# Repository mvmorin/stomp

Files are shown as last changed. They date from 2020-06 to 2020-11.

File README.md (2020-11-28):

# Stomp
Split, staggered column 40% keyboard. Designed in KiCad with symbols and footprints from [keyboard-parts](https://github.com/mvmorin/keyboard-parts) library.

# Features
* Low profile and flat-bottom design to be put on top of laptop keyboards.
* Extra large stagger for pinky columns.
* Based on a standard 40% 4x12 layout but only contains the reachable keys. It should be compatible with most 40% 4x12 layouts.
* Only a single Teensy or Pro-Micro-compatible controller board needed.
* Full FR4 (PCB) design, including backplate, for easy single order manufacturing.
* Both MX and Alps plates.

# PCB and Plate files
The production files for the latest version can be found in the 'gerber' directory. They have been test printed at [JLCPCB](https://jlcpcb.com/). Any notes from the test prints can be found below.

## Test Print Comments
The mounting pin holes for 5-pin MX-switches are bit tighter than I would have preferred. They are perfectly usable with the Ink Blacks I tested them but they will be enlarged in any potential future revisions.

# Licenses


This project is released under the [Creative Commons CC-BY-SA 4.0](https://creativecommons.org/licenses/by-sa/4.0/legalcode) license, Copyright (c) Martin Morin 2020.
Some footprints and symbols are based on parts from the [KiCad libraries](https://kicad-pcb.org/libraries/), released under the same [CC-BY-SA 4.0](https://creativecommons.org/licenses/by-sa/4.0/legalcode) license.

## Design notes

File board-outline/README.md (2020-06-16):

# Board Outline
It based on an export of the switch cutouts and is drawn as a parametric sketch.

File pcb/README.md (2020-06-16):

# Base PCB
The footprints contains all information for the plate. The switch cutouts and the plate silk-screen layer are exported via the *eco1*, *eco2*, and *cmts* layers and are then imported in the backplate PCB drawing. The board-outline/edge-cuts is imported from the *board-outline* directory.

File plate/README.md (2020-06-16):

# Plates
The switch cutouts and the plate silk-screen are imported from the base PCB drawing. The edge-cuts are imported from the *board-outline* directory.

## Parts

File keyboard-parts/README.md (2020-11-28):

# Keyboard Parts
KiCad library of MX and Alps compatible footprints and other miscellaneous footprints and symbols.

# Design
The main focus is the ease of PCB and plate creation. The switch footprints and symbol already have the diodes included. This eliminates almost half of the components and traces. Each switch footprint also comes with the corresponding plate-cutout for both MX and Alps switches as well as a silk-screen layer for the plate. The PCB can then serve as the master for the plate with the corresponding layers being exported for use in the plate design. The cutouts are mainly aimed at PCB/FR4 plates and are/will be dimensioned to accommodate the looser tolerances of PCB-milling.

# Features
* Combined switch-and-diode footprints.
* *eco1*-layer: Outline for MX cutouts.
* *eco2*-layer: Outline for Alps cutouts.
* *cmts*-layer: Silk-screen for plate.

The main benefit of these footprints is the extra information of the keyboard backplate they contain. To easily export these features to the backplate KiCad project, the *eco1*, *eco2*, and *cmts* layers of all other footprints used need to either be empty or contain the corresponding information.

# Known Issues
* ~~MX stabilizer cutout are tight but fully usable.~~
* ~~Mounting pin holes for 5-pin MX switches are tight but fully usable.~~

# Untested Footprints
Footprint features that not have been test printed/manufactured:
* The new 0.1mm larger MX stabilizer cutouts and mounting pin holes for 5-pn MX switches.

# Licenses


The library is released under the [Creative Commons CC-BY-SA 4.0](https://creativecommons.org/licenses/by-sa/4.0/legalcode) license, Copyright (c) Martin Morin 2020.
Some footprints and symbols are based on parts from the [KiCad libraries](https://kicad-pcb.org/libraries/), released under the same [CC-BY-SA 4.0](https://creativecommons.org/licenses/by-sa/4.0/legalcode) license.

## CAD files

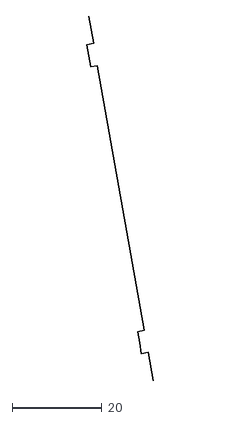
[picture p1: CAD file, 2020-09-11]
board-outline/magnet-sidecuts.dxf
14.7 x 81.2

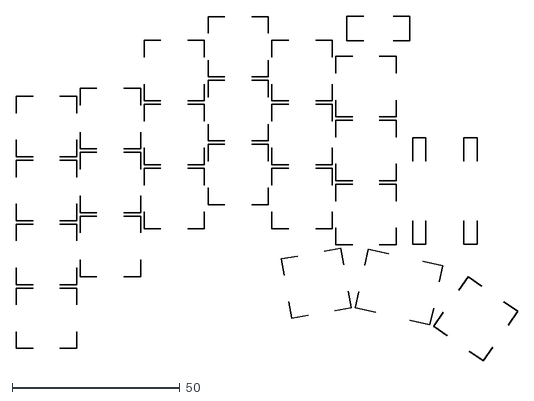
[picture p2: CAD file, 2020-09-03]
plate/outlines/pcb-Cmts_User.dxf
149.5 x 102.7

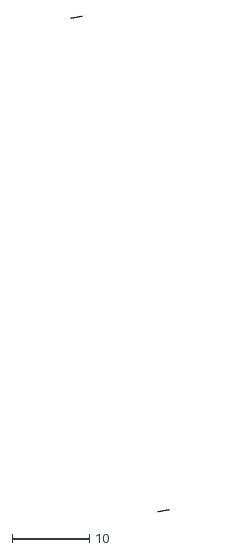
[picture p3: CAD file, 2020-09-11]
board-outline/magnet-pos.dxf
12.8 x 64.3

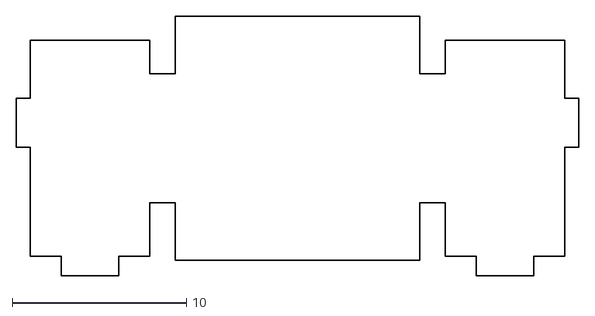
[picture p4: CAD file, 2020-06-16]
keyboard-parts/plate-cutouts/mx_stab_2u.dxf
32.3 x 14.9

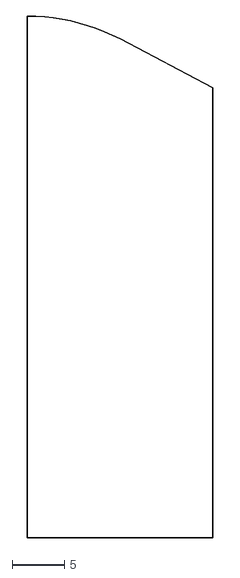
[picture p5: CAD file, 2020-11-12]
mcu-dummy/outline.dxf
17.8 x 49.9

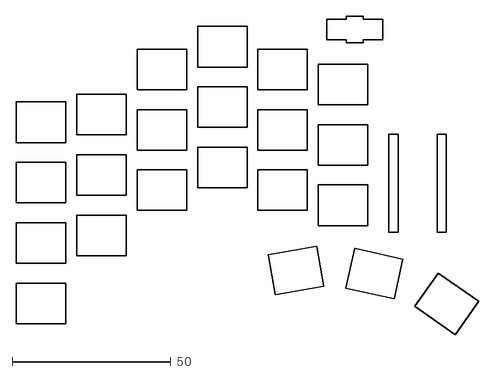
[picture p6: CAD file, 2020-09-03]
plate/outlines/pcb-Eco2_User.dxf
145.8 x 100.4

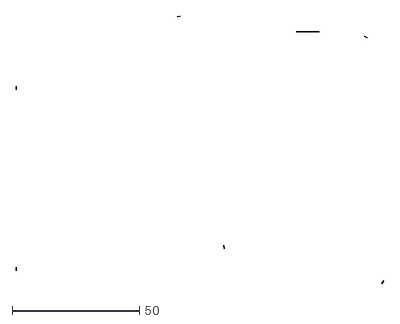
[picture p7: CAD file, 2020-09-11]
board-outline/header-pos.dxf
144.8 x 105.3

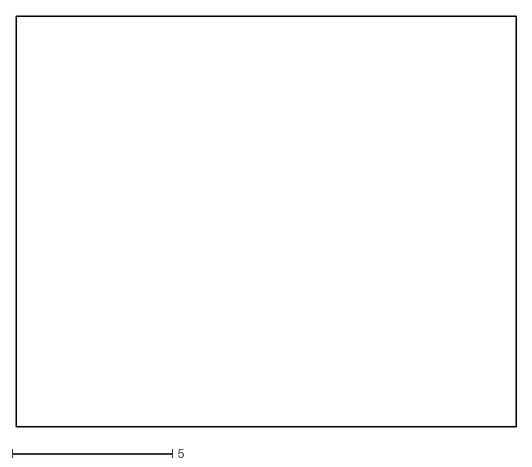
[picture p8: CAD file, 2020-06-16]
keyboard-parts/plate-cutouts/alps.dxf
15.6 x 12.8

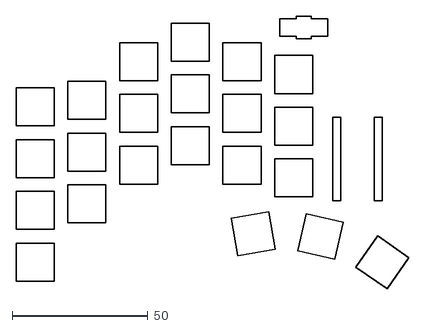
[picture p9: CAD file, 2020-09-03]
plate/outlines/pcb-Eco1_User.dxf
144.7 x 100.5

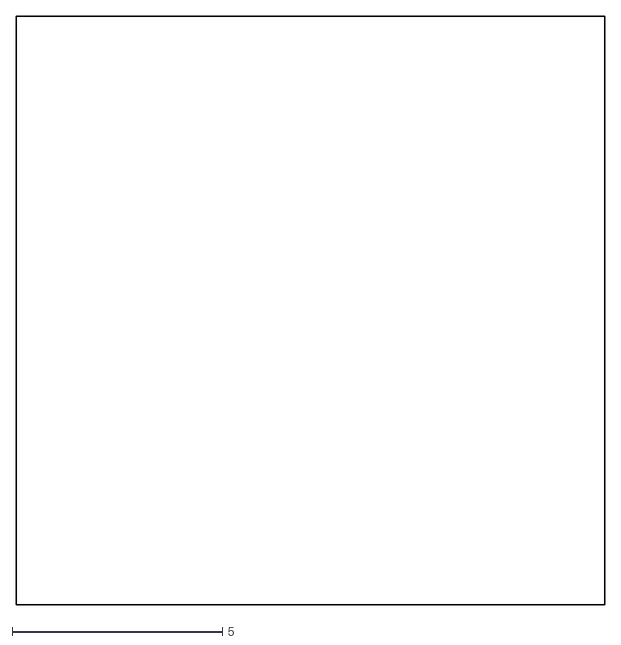
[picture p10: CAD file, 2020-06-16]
keyboard-parts/plate-cutouts/mx.dxf
14.0 x 14.0

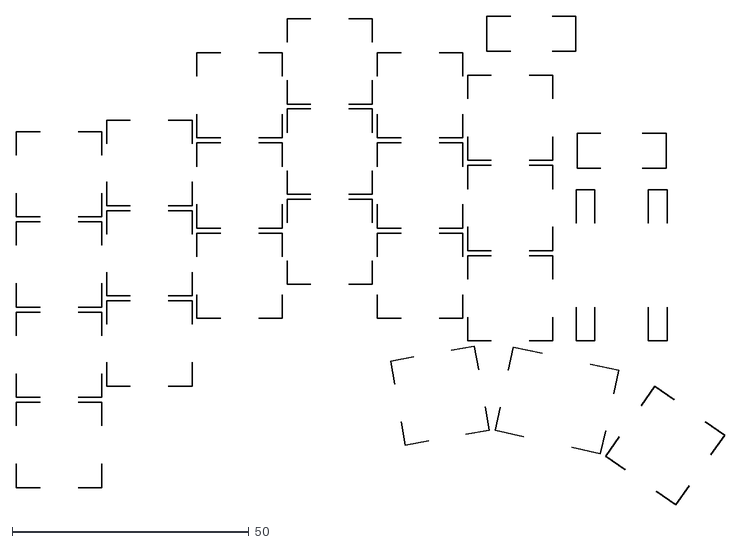
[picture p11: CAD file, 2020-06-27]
plate/outlines/plate-silk.dxf
149.5 x 103.2

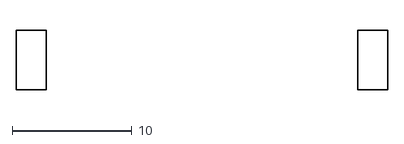
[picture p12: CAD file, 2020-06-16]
keyboard-parts/plate-cutouts/alps_stab_2u.dxf
31.0 x 5.00

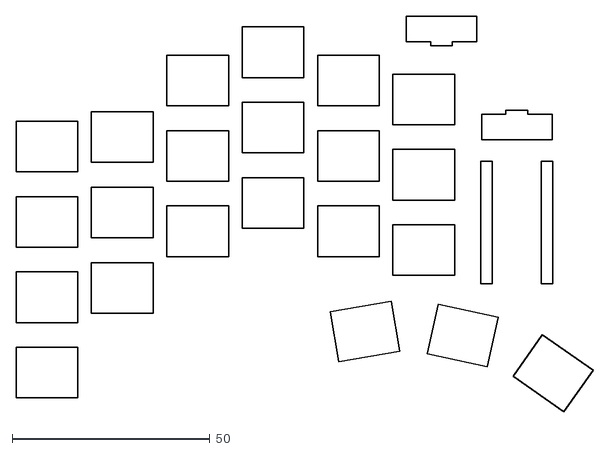
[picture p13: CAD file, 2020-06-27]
plate/outlines/alps-cutouts.dxf
145.8 x 99.9

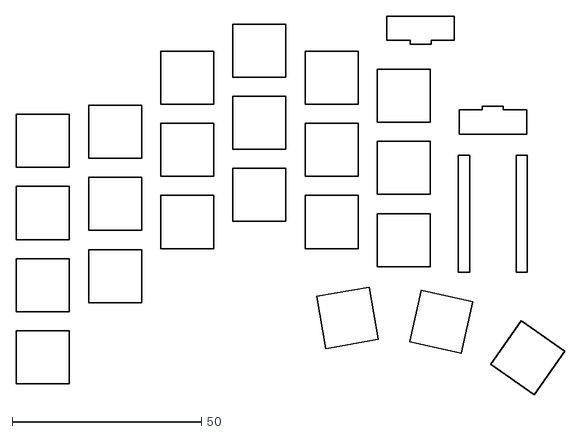
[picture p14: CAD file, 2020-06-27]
plate/outlines/mx-cutouts.dxf
144.7 x 99.9

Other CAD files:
keyboard-parts/plate-cutouts/plate_cutouts.FCStd
mcu-dummy/mcu-dummy-outline.fcstd
board-outline/board-outline.FCStd
board-outline/board-outline.dxf
board-outline/header_pos.dxf

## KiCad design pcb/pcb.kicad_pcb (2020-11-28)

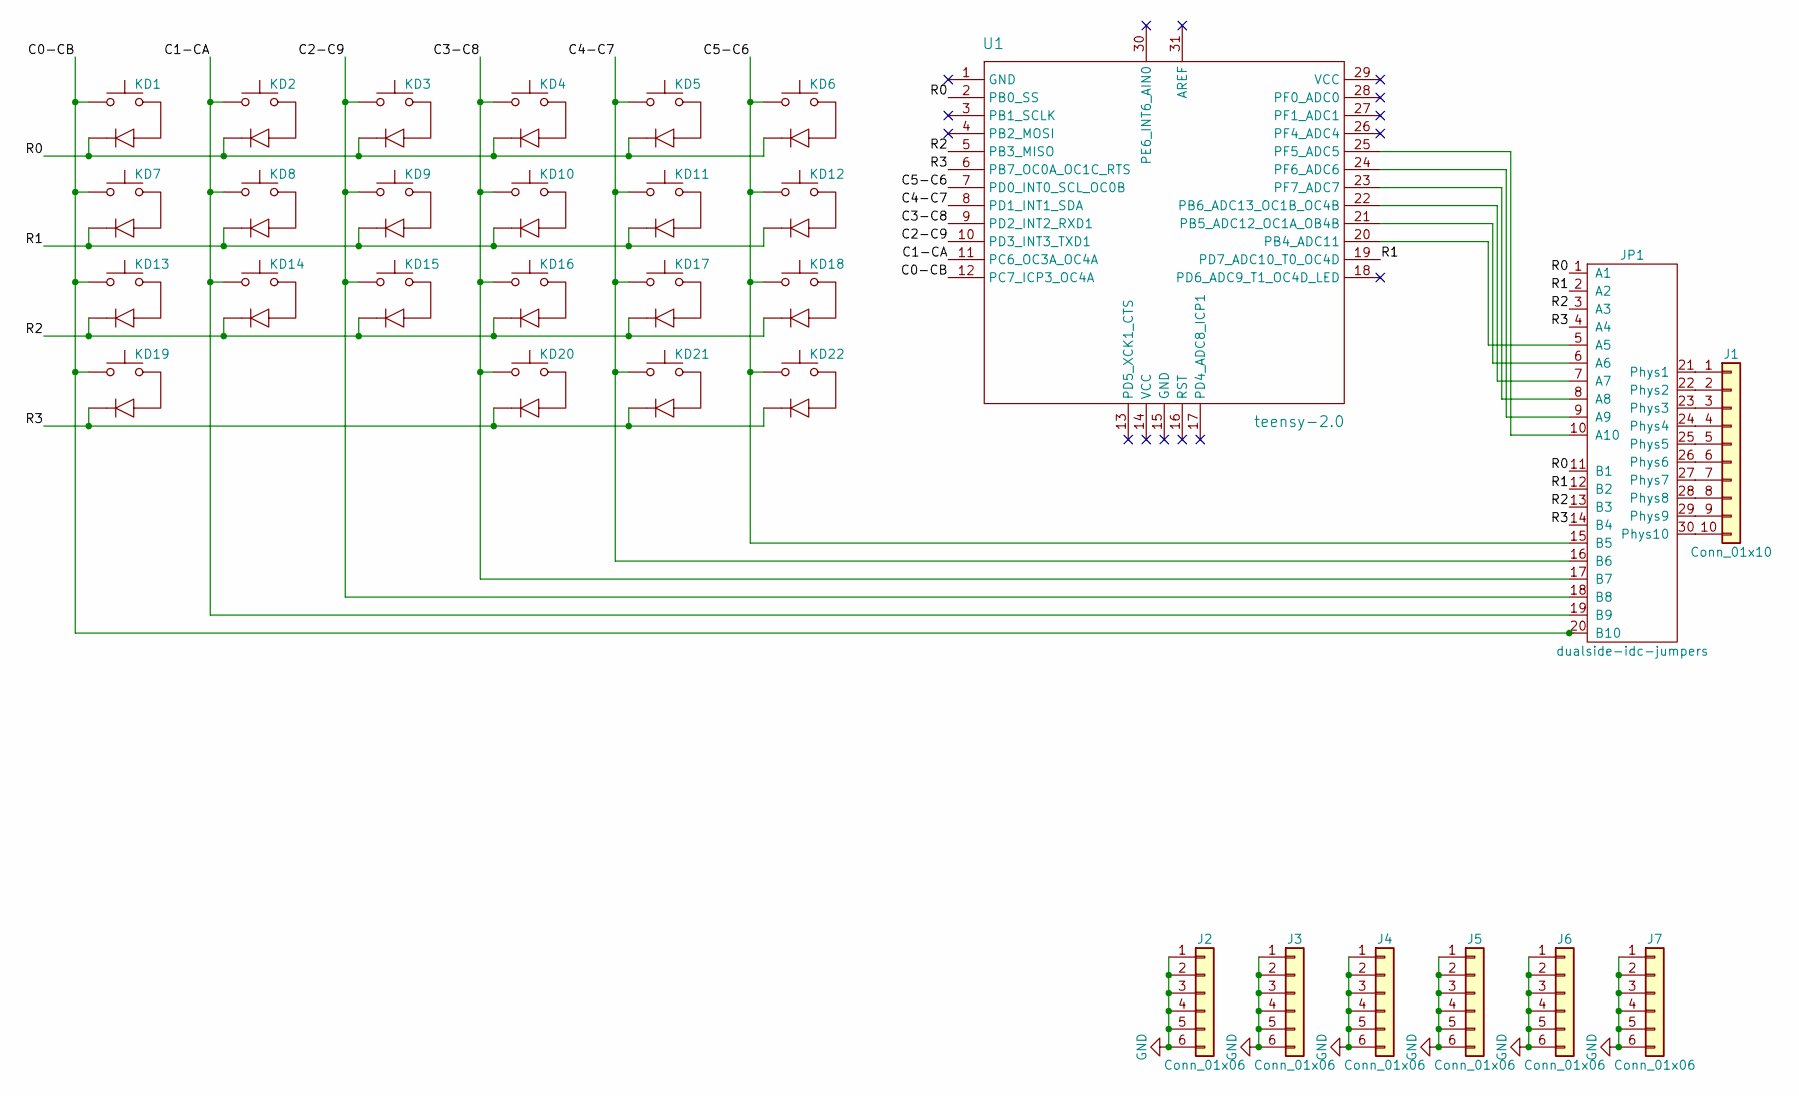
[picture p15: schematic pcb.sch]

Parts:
J1: Conn_01x10; idc-header-dualside_2x05_2.54mm
J2, J3, J4, J5, J6, J7: Conn_01x06; header_sym_1x06_2.54mm
JP1: dualside-idc-jumpers
KD1, KD2, KD3, KD4, KD5, KD6, KD7, KD8, KD9, KD10, KD11, KD12, KD13, KD14, KD15, KD16, KD17, KD18, KD19, KD20, KD22: switch-w-diode; mxalps_w_diode_R_100U_dualside
KD21: switch-w-diode; mxalps_w_diode_R_125U_dualside
U1: teensy-2.0; teensy2.0_dualside

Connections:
/C0-CB: JP1.20 (B10), KD1.1 (A), KD7.1 (A), KD13.1 (A), KD19.1 (A), U1.12 (PC7_ICP3_OC4A)
/C1-CA: JP1.19 (B9), KD2.1 (A), KD8.1 (A), KD14.1 (A), U1.11 (PC6_OC3A_OC4A)
/C2-C9: JP1.18 (B8), KD3.1 (A), KD9.1 (A), KD15.1 (A), U1.10 (PD3_INT3_TXD1)
/C3-C8: JP1.17 (B7), KD4.1 (A), KD10.1 (A), KD16.1 (A), KD20.1 (A), U1.9 (PD2_INT2_RXD1)
/C4-C7: JP1.16 (B6), KD5.1 (A), KD11.1 (A), KD17.1 (A), KD21.1 (A), U1.8 (PD1_INT1_SDA)
/C5-C6: JP1.15 (B5), KD6.1 (A), KD12.1 (A), KD18.1 (A), KD22.1 (A), U1.7 (PD0_INT0_SCL_OC0B)
/R0: JP1.1 (A1), JP1.11 (B1), KD1.2 (K), KD2.2 (K), KD3.2 (K), KD4.2 (K), KD5.2 (K), KD6.2 (K), U1.2 (PB0_SS)
/R1: JP1.2 (A2), JP1.12 (B2), KD7.2 (K), KD8.2 (K), KD9.2 (K), KD10.2 (K), KD11.2 (K), KD12.2 (K), U1.19 (PD7_ADC10_T0_OC4D)
/R2: JP1.3 (A3), JP1.13 (B3), KD13.2 (K), KD14.2 (K), KD15.2 (K), KD16.2 (K), KD17.2 (K), KD18.2 (K), U1.5 (PB3_MISO)
/R3: JP1.4 (A4), JP1.14 (B4), KD19.2 (K), KD20.2 (K), KD21.2 (K), KD22.2 (K), U1.6 (PB7_OC0A_OC1C_RTS)
GND: J2.1, J2.2, J2.3, J2.4, J2.5, J2.6, J3.1, J3.2, J3.3, J3.4, J3.5, J3.6, J4.1, J4.2, J4.3, J4.4, J4.5, J4.6, J5.1, J5.2, J5.3, J5.4, J5.5, J5.6, J6.1, J6.2, J6.3, J6.4, J6.5, J6.6, J7.1, J7.2, J7.3, J7.4, J7.5, J7.6
unnamed: J1.1, JP1.21 (Phys1)
unnamed: J1.2, JP1.22 (Phys2)
unnamed: J1.3, JP1.23 (Phys3)
unnamed: J1.4, JP1.24 (Phys4)
unnamed: J1.5, JP1.25 (Phys5)
unnamed: J1.6, JP1.26 (Phys6)
unnamed: J1.7, JP1.27 (Phys7)
unnamed: J1.8, JP1.28 (Phys8)
unnamed: J1.9, JP1.29 (Phys9)
unnamed: J1.10, JP1.30 (Phys10)
unnamed: JP1.5 (A5), U1.20 (PB4_ADC11)
unnamed: JP1.6 (A6), U1.21 (PB5_ADC12_OC1A_OB4B)
unnamed: JP1.7 (A7), U1.22 (PB6_ADC13_OC1B_OC4B)
unnamed: JP1.8 (A8), U1.23 (PF7_ADC7)
unnamed: JP1.9 (A9), U1.24 (PF6_ADC6)
unnamed: JP1.10 (A10), U1.25 (PF5_ADC5)

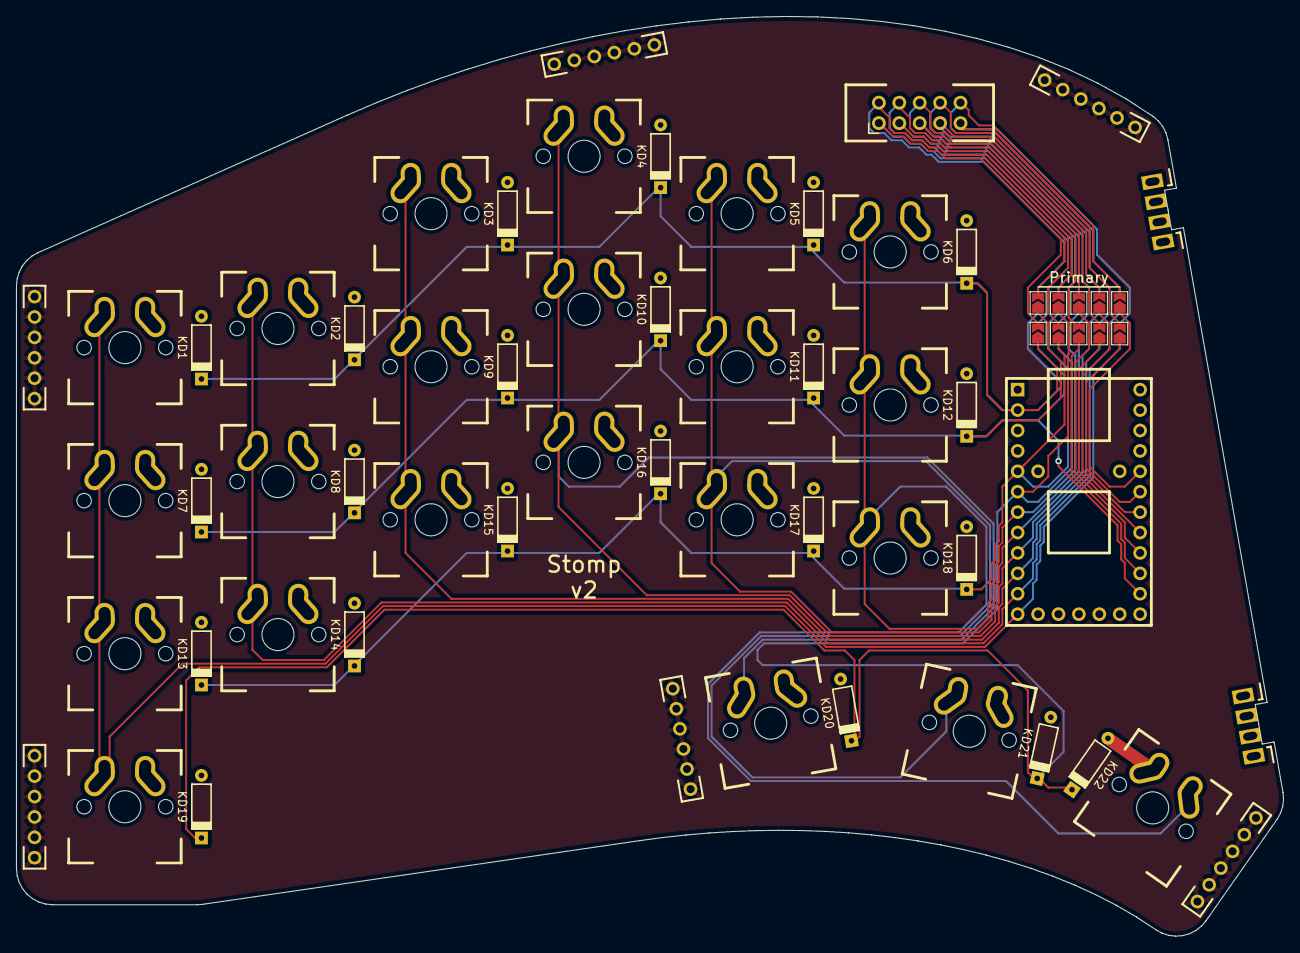
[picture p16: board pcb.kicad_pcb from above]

Board: 2 copper layers, 157.7 x 114.5 mm, 31 parts (1 on the bottom side), 27 nets.

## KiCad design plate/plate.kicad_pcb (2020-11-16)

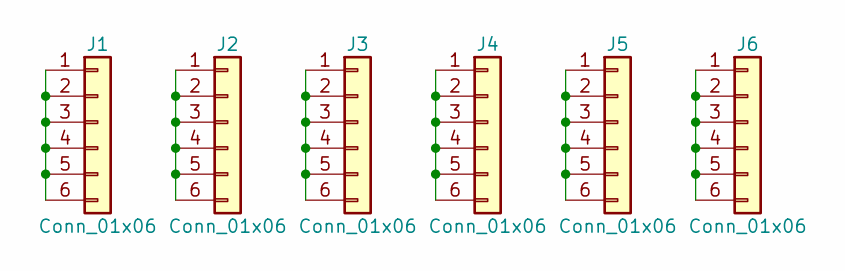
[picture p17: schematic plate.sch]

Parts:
J1, J2, J3, J4, J5, J6: Conn_01x06; header_sym_1x06_2.54mm

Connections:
unnamed: J1.1, J1.2, J1.3, J1.4, J1.5, J1.6
unnamed: J2.1, J2.2, J2.3, J2.4, J2.5, J2.6
unnamed: J3.1, J3.2, J3.3, J3.4, J3.5, J3.6
unnamed: J4.1, J4.2, J4.3, J4.4, J4.5, J4.6
unnamed: J5.1, J5.2, J5.3, J5.4, J5.5, J5.6
unnamed: J6.1, J6.2, J6.3, J6.4, J6.5, J6.6

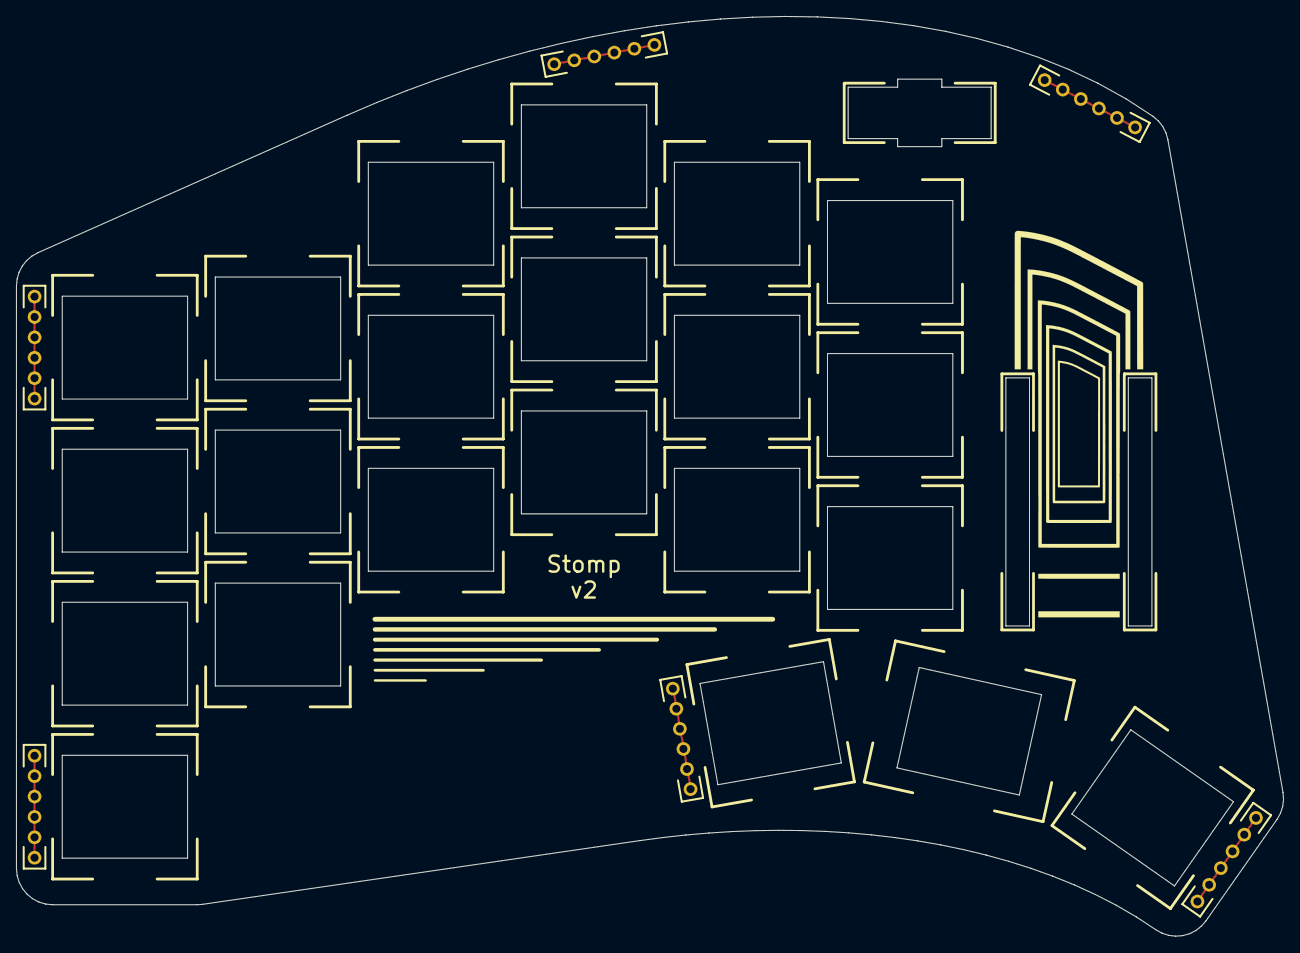
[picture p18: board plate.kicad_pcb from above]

Board: 2 copper layers, 157.7 x 114.5 mm, 6 parts (0 on the bottom side), 6 nets.

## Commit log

2020-06-16 Squashed 'keyboard-parts/' content from commit 7592995
    git-subtree-dir: keyboard-parts
    git-subtree-split: 75929951316423486571924b044501165a41824c
    [alps.dxf, alps_stab_2u.dxf, mx.dxf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]
2020-06-16 Create schematic and start on board
    [pcb.kicad_pcb, pcb.sch]
2020-06-21 Add/remove teensy and header footprints for dualsided keyboards
2020-06-21 Final routing of base pcb. Outline left.
    [pcb.kicad_pcb, pcb.sch]
2020-06-21 Finish base pcb, decorations left
    [board-outline.FCStd, board-outline.dxf, pcb.kicad_pcb]
2020-06-25 Add/update double sided footprints
2020-06-25 Add headers for board interconnect
    [pcb.kicad_pcb, pcb.sch]
2020-06-25 Rotate header to avoid twisting ribbon cable
    [pcb.kicad_pcb]
2020-06-26 Fatter silk and tighter headers cutouts in teensy and IDC
2020-06-26 Add 1x6 header and fix reference in teensy
2020-06-26 Update board outline
    [board-outline.FCStd, board-outline.dxf, pcb.kicad_pcb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]
2020-06-26 Add logos to main pcb
    [pcb.kicad_pcb]
2020-06-27 Add plate
    [alps-cutouts.dxf, mx-cutouts.dxf, pcb.kicad_pcb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]
2020-06-27 Update component 3d models
    [pcb.kicad_pcb, pcb.sch, plate.kicad_pcb]
2020-06-27 Remove arcs on silk
    JLCPCB's gerber viewer draws arcs reversed, might not be a real problem
    but why bother
    [pcb.kicad_pcb, plate.kicad_pcb]
2020-06-27 Add gerbers
2020-07-13 Fix minor silk-screen misses and alignment
    [pcb.kicad_pcb, plate.kicad_pcb]
2020-07-14 Change board outline
    [board-outline.FCStd, board-outline.dxf, pcb-Cmts_User.dxf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]
2020-07-14 Fix one header
    [pcb.kicad_pcb, plate.kicad_pcb]
2020-07-16 Finish refinement of board outline
    [board-outline.FCStd, board-outline.dxf, pcb-Cmts_User.dxf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]
2020-07-16 Change pin for column B to avoid teensy LED
    [pcb.kicad_pcb, pcb.sch]
2020-07-16 Slight reposition and reroute of inter-pcb-header
    [pcb-Cmts_User.dxf, pcb-Eco1_User.dxf, pcb-Eco2_User.dxf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]
2020-09-03 Use single IDC header and prep outline for magnets
    [board-outline.FCStd, board-outline.dxf, pcb-Cmts_User.dxf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]
2020-09-11 Add higher resolution outline curves and magnet supports
    [board-outline.FCStd, board-outline.dxf, magnet-sidecuts.dxf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]
2020-11-12 Add two row teensy footprint for mcu-dummy
2020-11-12 Add mcu-dummy for secondary side and new logos on plate
    [mcu-dummy-outline.fcstd, mcu-dummy.kicad_pcb, outline.dxf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]
2020-11-13 Change line widths of graphics to balance the look better
    [mcu-dummy.kicad_pcb, plate.kicad_pcb]
2020-11-16 Update version number to v2 and add new gerbers
    [mcu-dummy.kicad_pcb, pcb.kicad_pcb, plate.kicad_pcb]
2020-11-28 Squashed 'keyboard-parts/' changes from 7592995..d7591ea
    d7591ea Update README.md
    9f18485 Add two row teensy footprint for mcu-dummy
    8ce1f52 Add higher resolution outline curves and magnet supports
    7473e23 Use single IDC header and prep outline for magnets
    80d8032 Update component 3d models
    6c1f2c6 Add 1x6 header and fix reference in teensy
    bab489d Fatter silk and tighter headers cutouts in teensy and IDC
    47fce25 Add/update double sided footprints
    03ca6c9 Add/remove teensy and header footprints for dualsided keyboards
    792f574 Add new double sided parts
    git-subtree-split: d7591ea33b660919236fcc919a326ff28b49c6a0
    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
2020-11-28 Enlarge pin-holes for 5-pin MX switches
    [pcb.kicad_pcb]
